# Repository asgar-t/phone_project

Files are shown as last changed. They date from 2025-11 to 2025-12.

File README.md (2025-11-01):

# 📱 Phone Project

A custom embedded hardware project built around an STM32 microcontroller and Quectel EC25 modem.  
The goal is to design, assemble, and program a complete phone system from the ground up — starting with hardware validation and moving toward a full integrated board.

---

## 🚀 Project Overview

**Step 1 — Hardware Verification (current step)** 
- Bring-up of the main board and peripheral circuits  
- Validate power rails, charging system, and USB interface  
- Test modem communication (EC25) and antenna performance  
- Ensure STM32 programming and serial communication are functional  

**Step 2 — Full System Integration**
- Run the STM32 firmware with modem control and battery management  
- Implement power sequencing and graceful shutdown logic  
- Test full end-to-end operation (voice/data + MCU control)  
- Optimize PCB layout and firmware reliability for production

---

## 🧠 Skills Demonstrated
- **PCB Design:** High-speed routing, impedance control, power delivery, and signal integrity  
- **Embedded Programming:** STM32 firmware (C), peripheral interfacing (UART, USB, GPIO, ADC)  
- **Power Systems:** Battery charging, voltage regulation, and load-sharing design  
- **System Integration:** Combining modem, MCU, and power management into a cohesive embedded system  

---

## ⚙️ Technologies & Components
- **MCU:** STM32 L4 Series
- **Modem:** Quectel EC25-AF  
- **Power:** USB-C input, Li-ion battery, charger IC 
- **Communication:** USB, UART, CAN 
- **Tools:** KiCad, STM32CubeIDE

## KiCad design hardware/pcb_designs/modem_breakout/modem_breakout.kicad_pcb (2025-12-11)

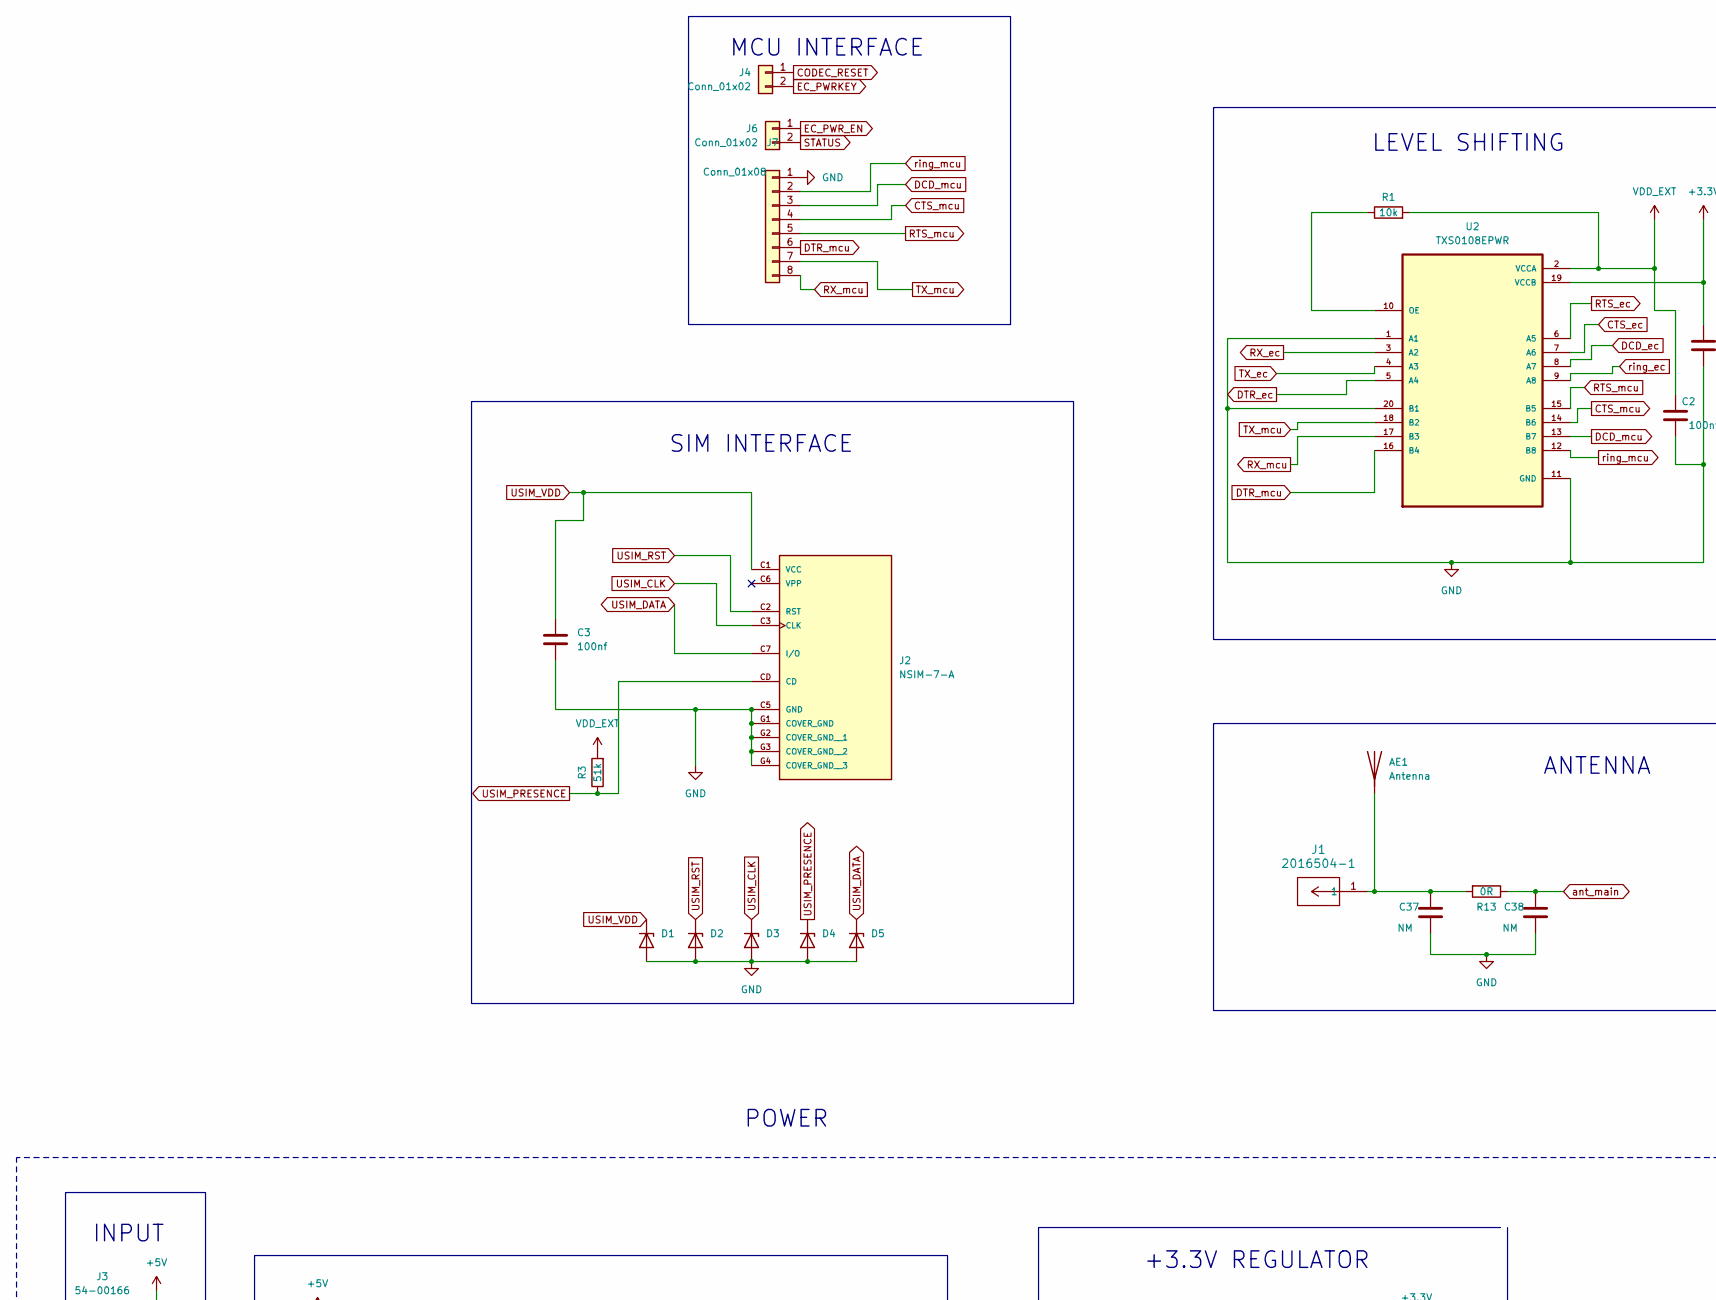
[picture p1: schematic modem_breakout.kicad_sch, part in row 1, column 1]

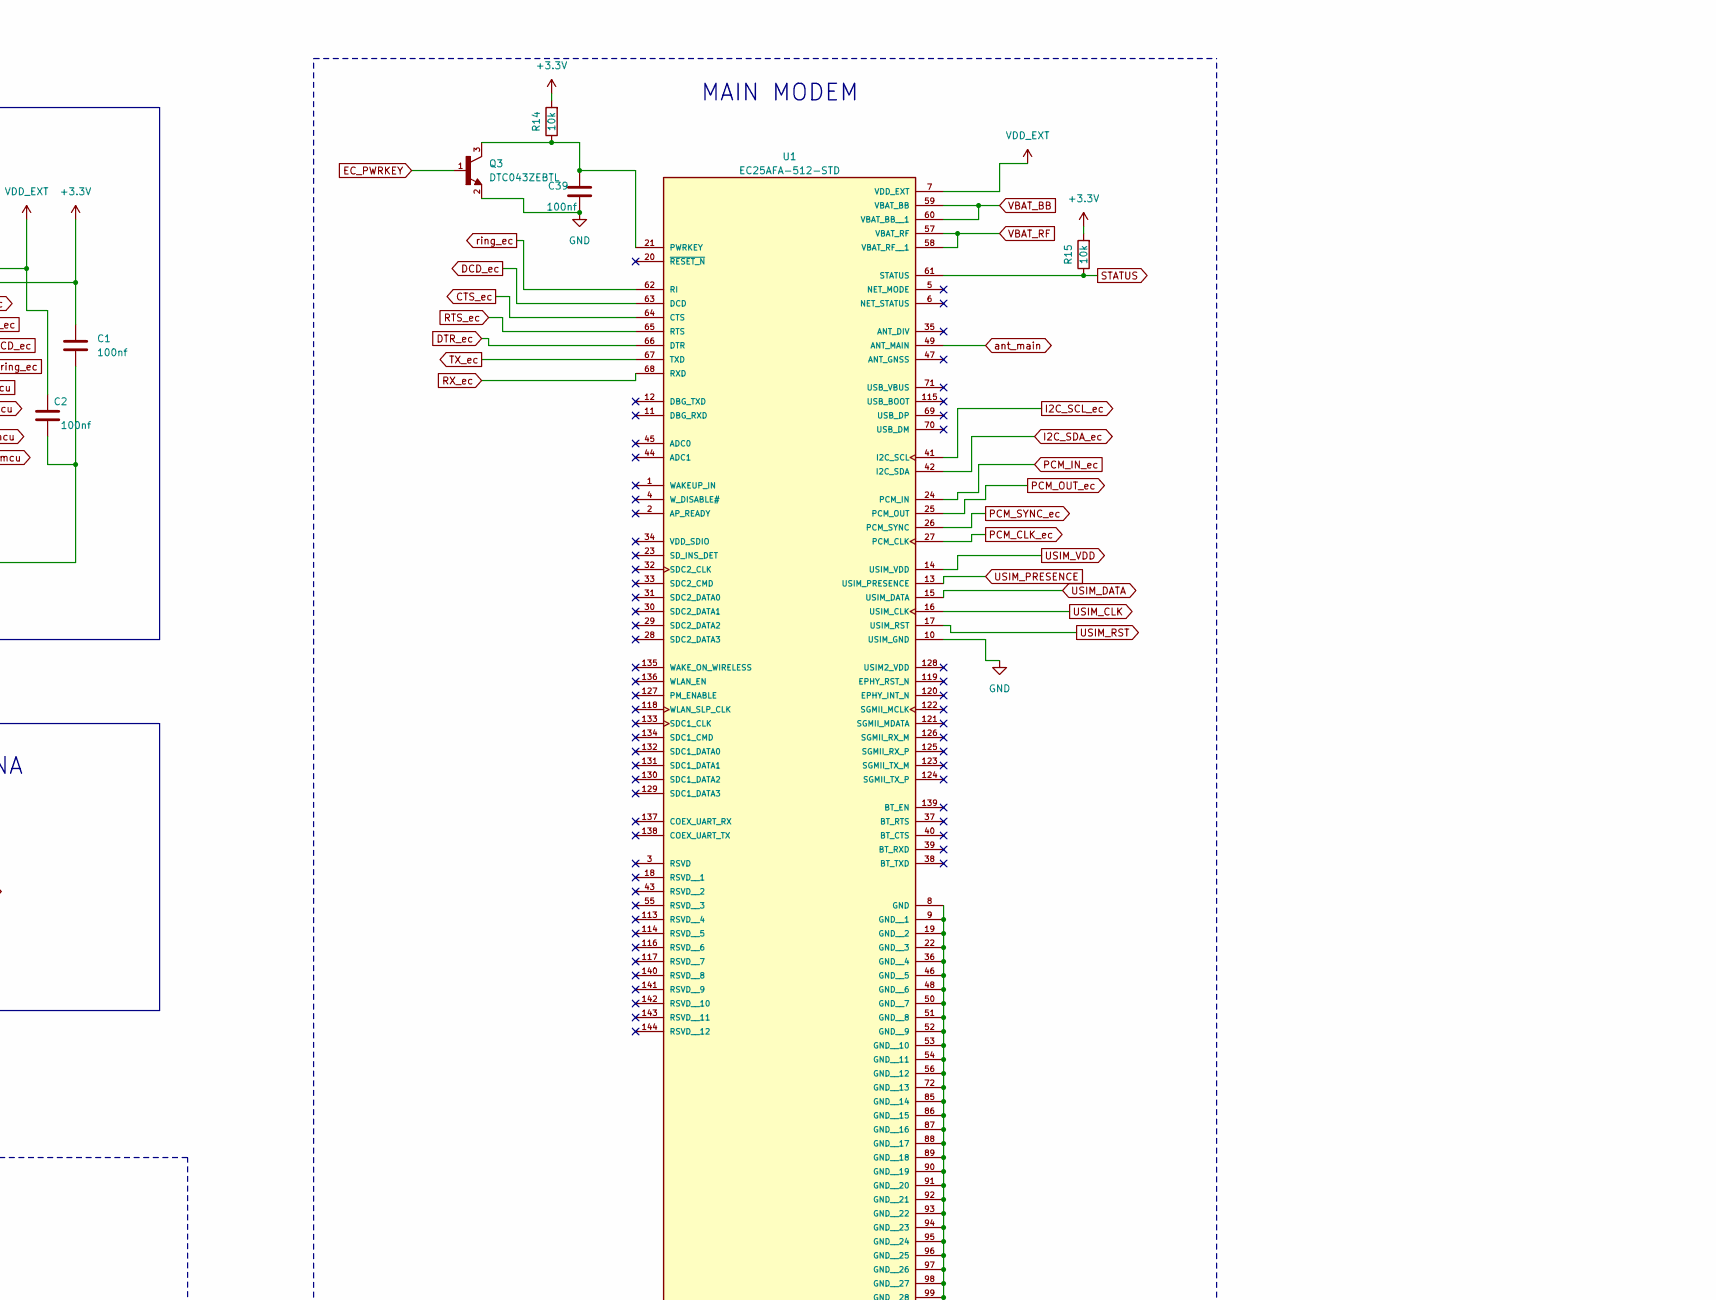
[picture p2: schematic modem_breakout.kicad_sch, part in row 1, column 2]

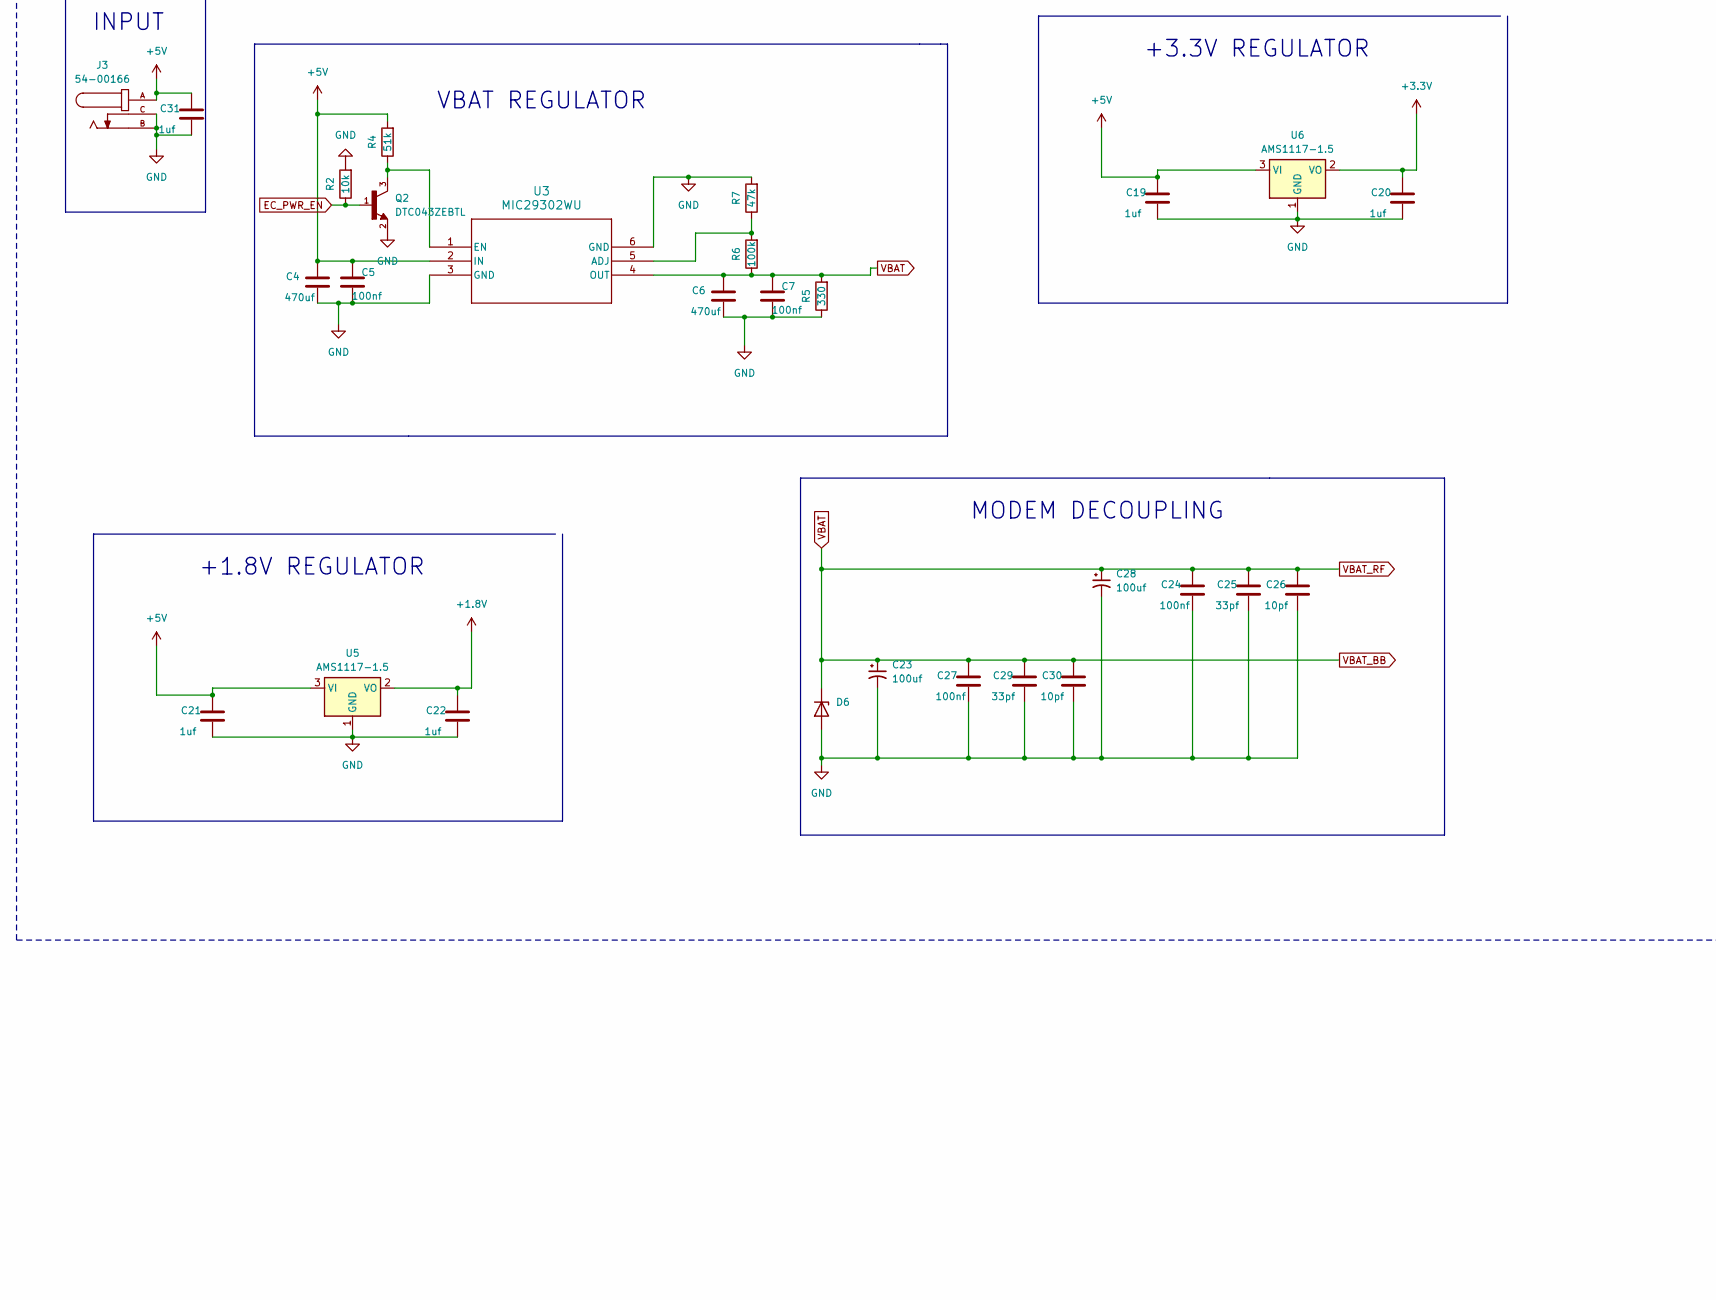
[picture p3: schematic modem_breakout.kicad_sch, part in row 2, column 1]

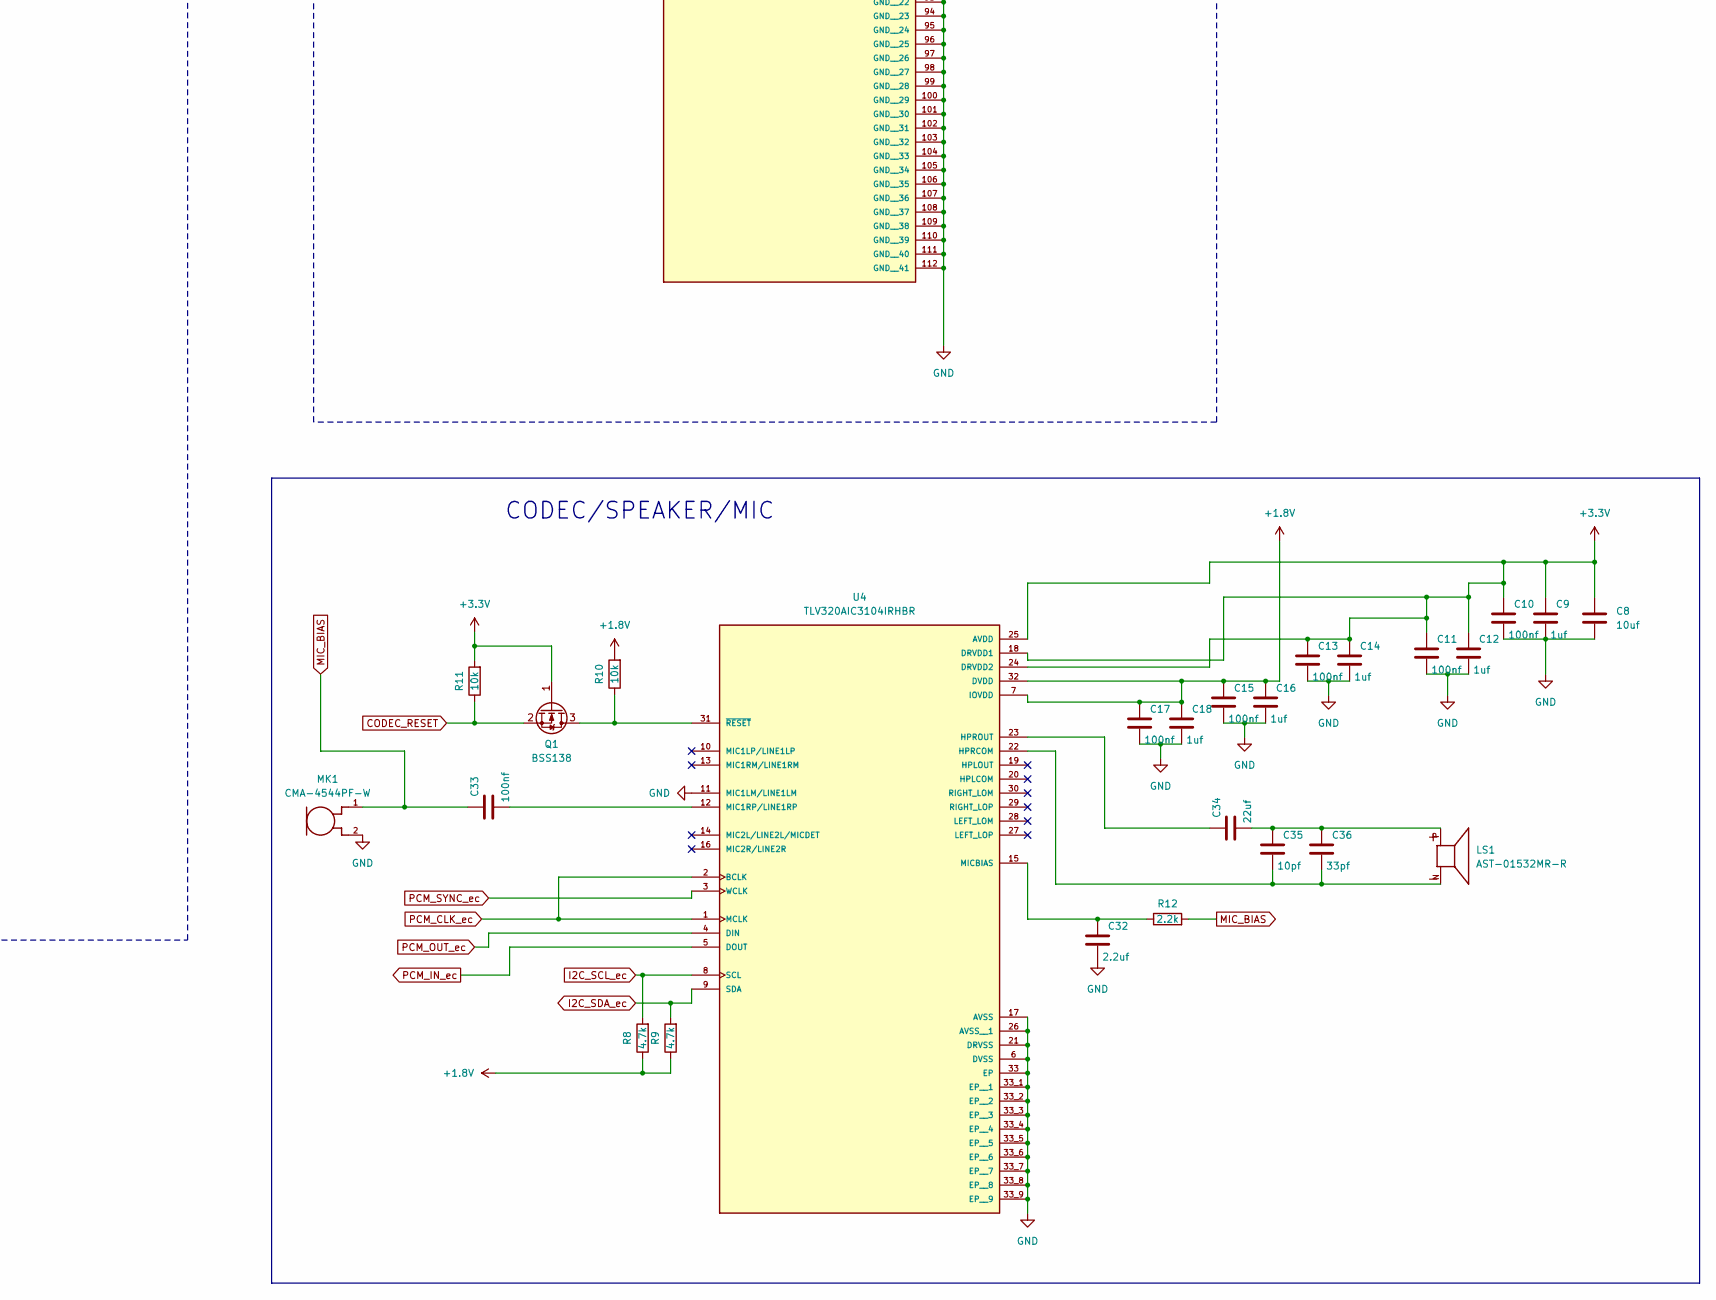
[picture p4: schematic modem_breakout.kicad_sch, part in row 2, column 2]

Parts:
AE1: Antenna
C1, C2, C3, C5, C7, C24, C27, C33, C39: 100nf; C_0805_2012Metric_Pad1.18x1.45mm_HandSolder
C4, C6: 470uf; C_0805_2012Metric_Pad1.18x1.45mm_HandSolder
C8: 10uf; C_0402_1005Metric_Pad0.74x0.62mm_HandSolder
C9, C12, C14, C16, C18: 1uf; C_0402_1005Metric_Pad0.74x0.62mm_HandSolder
C10, C11, C13, C15, C17: 100nf; C_0402_1005Metric_Pad0.74x0.62mm_HandSolder
C19, C20, C21, C22, C31: 1uf; C_0805_2012Metric_Pad1.18x1.45mm_HandSolder
C23, C28: 100uf; C_0805_2012Metric_Pad1.18x1.45mm_HandSolder
C25, C29, C36: 33pf; C_0805_2012Metric_Pad1.18x1.45mm_HandSolder
C26, C30, C35: 10pf; C_0805_2012Metric_Pad1.18x1.45mm_HandSolder
C32: 2.2uf; C_0805_2012Metric_Pad1.18x1.45mm_HandSolder
C34: 22uf; C_0805_2012Metric_Pad1.18x1.45mm_HandSolder
C37, C38: NM; C_0805_2012Metric_Pad1.18x1.45mm_HandSolder
D1, D2, D3, D4, D5, D6: PTVS12VZ1USK; Nexperia_DSN1608-2_1.6x0.8mm
J1: 2016504-1; CONN1_2016504-1_TEC
J2: NSIM-7-A; new_sim; PARTREV 1.0
J3: 54-00166; barrel jack; PARTREV A
J4, J6: Conn_01x02; PinHeader_1x02_P2.54mm_Vertical
J7: Conn_01x08; PinHeader_1x08_P2.54mm_Vertical
LS1: AST-01532MR-R; SPKR_AST-01532MR-R; PARTREV A
MK1: CMA-4544PF-W; MIC_CMA-4544PF-W
Q1: BSS138; SOT-23
Q2, Q3: DTC043ZEBTL; SOTFL50P160X85-3N; PARTREV 002
R1, R2, R14, R15: 10k; C_0805_2012Metric_Pad1.18x1.45mm_HandSolder
R3, R4: 51k; C_0805_2012Metric_Pad1.18x1.45mm_HandSolder
R5: 330; C_0805_2012Metric_Pad1.18x1.45mm_HandSolder
R6: 100k; C_0805_2012Metric_Pad1.18x1.45mm_HandSolder
R7: 47k; C_0805_2012Metric_Pad1.18x1.45mm_HandSolder
R8, R9: 4.7k; C_0805_2012Metric_Pad1.18x1.45mm_HandSolder
R10, R11: 10k; C_0402_1005Metric_Pad0.74x0.62mm_HandSolder
R12: 2.2k; C_0805_2012Metric_Pad1.18x1.45mm_HandSolder
R13: 0R; C_0805_2012Metric_Pad1.18x1.45mm_HandSolder
U1: EC25AFA-512-STD; modem
U2: TXS0108EPWR; uart_translator
U3: MIC29302WU; vreg
U4: TLV320AIC3104IRHBR; new_codec
U5, U6: AMS1117-1.5; SOT-223-3_TabPin2

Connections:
+1.8V: C15.1, C16.1, C17.1, C18.1, C22.1, R8.1, R9.1, R10.2, U4.7 (IOVDD), U4.32 (DVDD), U5.2 (VO)
+3.3V: C1.1, C8.1, C9.1, C10.1, C11.1, C12.1, C13.1, C14.1, C20.1, Q1.1 (G), R11.2, R14.2, R15.2, U2.19 (VCCB), U4.18 (DRVDD1), U4.24 (DRVDD2), U4.25 (AVDD), U6.2 (VO)
+5V: C4.1, C5.1, C19.1, C21.1, C31.1, J3.A, R4.2, U3.2 (IN), U5.3 (VI), U6.3 (VI)
CODEC_RESET: J4.1, Q1.2 (S), R11.1
CTS_ec: U1.64 (CTS), U2.7 (A6)
CTS_mcu: J7.4, U2.14 (B6); also elsewhere on the board
DCD_ec: U1.63 (DCD), U2.8 (A7)
DCD_mcu: J7.3, U2.13 (B7); also elsewhere on the board
DTR_ec: U1.66 (DTR), U2.5 (A4)
DTR_mcu: J7.6, U2.16 (B4); also elsewhere on the board
EC_PWRKEY: J4.2, Q3.1
EC_PWR_EN: J6.1, Q2.1, R2.1
GND: C1.2, C2.2, C3.2, C4.2, C5.2, C6.2, C7.2, C8.2, C9.2, C10.2, C11.2, C12.2, C13.2, C14.2, C15.2, C16.2, C17.2, C18.2, C19.2, C20.2, C21.2, C22.2, C23.2, C24.2, C25.2, C26.2, C27.2, C28.2, C29.2, C30.2, C31.2, C32.2, C37.2, C38.2, C39.2, D1.2 (A), D2.2 (A), D3.2 (A), D4.2 (A), D5.2 (A), D6.2 (A), J2.C5 (GND), J2.G1 (COVER_GND), J2.G2 (COVER_GND__1), J2.G3 (COVER_GND__2), J2.G4 (COVER_GND__3), J3.B, J3.C, J7.1, MK1.2, Q2.2, Q3.2, R2.2, R5.1, R7.2, U1.8 (GND), U1.9 (GND__1), U1.10 (USIM_GND), U1.19 (GND__2), U1.22 (GND__3), U1.36 (GND__4), U1.46 (GND__5), U1.48 (GND__6), U1.50 (GND__7), U1.51 (GND__8), U1.52 (GND__9), U1.53 (GND__10), U1.54 (GND__11), U1.56 (GND__12), U1.72 (GND__13), U1.85 (GND__14), U1.86 (GND__15), U1.87 (GND__16), U1.88 (GND__17), U1.89 (GND__18), U1.90 (GND__19), U1.91 (GND__20), U1.92 (GND__21), U1.93 (GND__22), U1.94 (GND__23), U1.95 (GND__24), U1.96 (GND__25), U1.97 (GND__26), U1.98 (GND__27), U1.99 (GND__28), U1.100 (GND__29), U1.101 (GND__30), U1.102 (GND__31), U1.103 (GND__32), U1.104 (GND__33), U1.105 (GND__34), U1.106 (GND__35), U1.107 (GND__36), U1.108 (GND__37), U1.109 (GND__38), U1.110 (GND__39), U1.111 (GND__40), U1.112 (GND__41), U2.1 (A1), U2.11 (GND), U2.20 (B1), U3.3 (GND), U3.6 (GND), U4.6 (DVSS), U4.11 (MIC1LM/LINE1LM), U4.17 (AVSS), U4.21 (DRVSS), U4.26 (AVSS__1), U4.33 (EP), U4.33_1 (EP__1), U4.33_2 (EP__2), U4.33_3 (EP__3), U4.33_4 (EP__4), U4.33_5 (EP__5), U4.33_6 (EP__6), U4.33_7 (EP__7), U4.33_8 (EP__8), U4.33_9 (EP__9), U5.1 (GND), U6.1 (GND); also elsewhere on the board
I2C_SCL_ec: R8.2, U1.41 (I2C_SCL), U4.8 (SCL)
I2C_SDA_ec: R9.2, U1.42 (I2C_SDA), U4.9 (SDA)
MIC_BIAS: C33.1, MK1.1, R12.2
unnamed: AE1.1, C37.1, J1.1, R13.2
unnamed: C34.2, C35.1, C36.1, LS1.P
unnamed: Q1.3 (D), R10.1, U4.31 (~RESET)
unnamed: C39.1, Q3.3, R14.1, U1.21 (PWRKEY)
unnamed: R1.1, U2.10 (OE)
unnamed: R6.2, R7.1, U3.5 (ADJ)
unnamed: Q2.3, R4.1, U3.1 (EN)
unnamed: C35.2, C36.2, LS1.N, U4.22 (HPRCOM)
unnamed: C34.1, U4.23 (HPROUT)
unnamed: C33.2, U4.12 (MIC1RP/LINE1RP)
unnamed: C32.1, R12.1, U4.15 (MICBIAS)
PCM_CLK_ec: U1.27 (PCM_CLK), U4.1 (MCLK), U4.2 (BCLK)
PCM_IN_ec: U1.24 (PCM_IN), U4.5 (DOUT)
PCM_OUT_ec: U1.25 (PCM_OUT), U4.4 (DIN)
PCM_SYNC_ec: U1.26 (PCM_SYNC), U4.3 (WCLK)
RTS_ec: U1.65 (RTS), U2.6 (A5)
RTS_mcu: J7.5, U2.15 (B5); also elsewhere on the board
RX_ec: U1.68 (RXD), U2.3 (A2)
RX_mcu: J7.8, U2.17 (B3); also elsewhere on the board
STATUS: J6.2, R15.1, U1.61 (STATUS)
TX_ec: U1.67 (TXD), U2.4 (A3)
TX_mcu: J7.7, U2.18 (B2); also elsewhere on the board
USIM_CLK: D3.1 (K), J2.C3 (CLK), U1.16 (USIM_CLK)
USIM_DATA: D5.1 (K), J2.C7 (I/O), U1.15 (USIM_DATA)
USIM_PRESENCE: D4.1 (K), J2.CD, R3.1, U1.13 (USIM_PRESENCE)
USIM_RST: D2.1 (K), J2.C2 (RST), U1.17 (USIM_RST)
USIM_VDD: C3.1, D1.1 (K), J2.C1 (VCC), U1.14 (USIM_VDD)
VBAT: C6.1, C7.1, C23.1, C24.1, C25.1, C26.1, C27.1, C28.1, C29.1, C30.1, D6.1 (K), R5.2, R6.1, U1.57 (VBAT_RF), U1.58 (VBAT_RF__1), U1.59 (VBAT_BB), U1.60 (VBAT_BB__1), U3.4 (OUT)
VDD_EXT: C2.1, R1.2, R3.2, U1.7 (VDD_EXT), U2.2 (VCCA)
ant_main: C38.1, R13.1, U1.49 (ANT_MAIN)
ring_ec: U1.62 (RI), U2.9 (A8)
ring_mcu: J7.2, U2.12 (B8); also elsewhere on the board

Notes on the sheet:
MCU INTERFACE
CODEC/SPEAKER/MIC
MODEM DECOUPLING
LEVEL SHIFTING
SIM INTERFACE
MAIN MODEM
ANTENNA
+3.3V REGULATOR
+1.8V REGULATOR
VBAT REGULATOR
POWER
INPUT

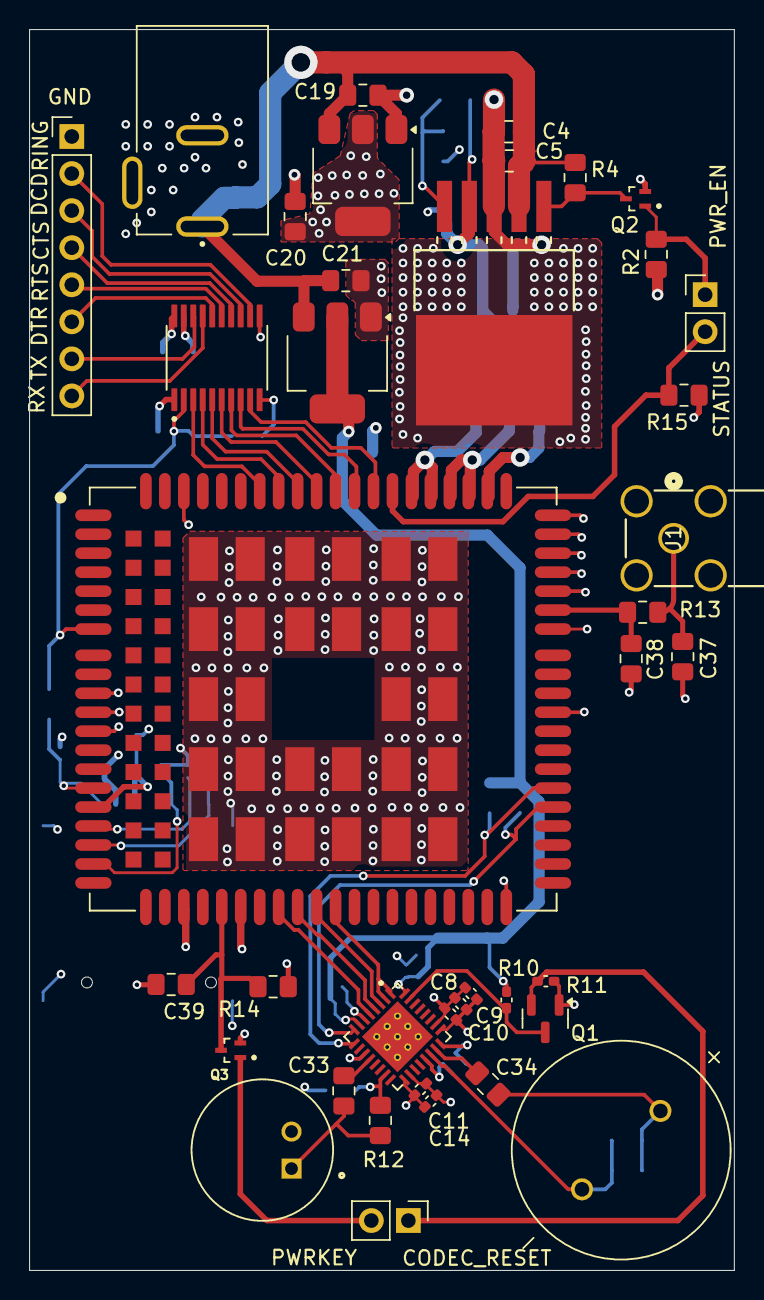
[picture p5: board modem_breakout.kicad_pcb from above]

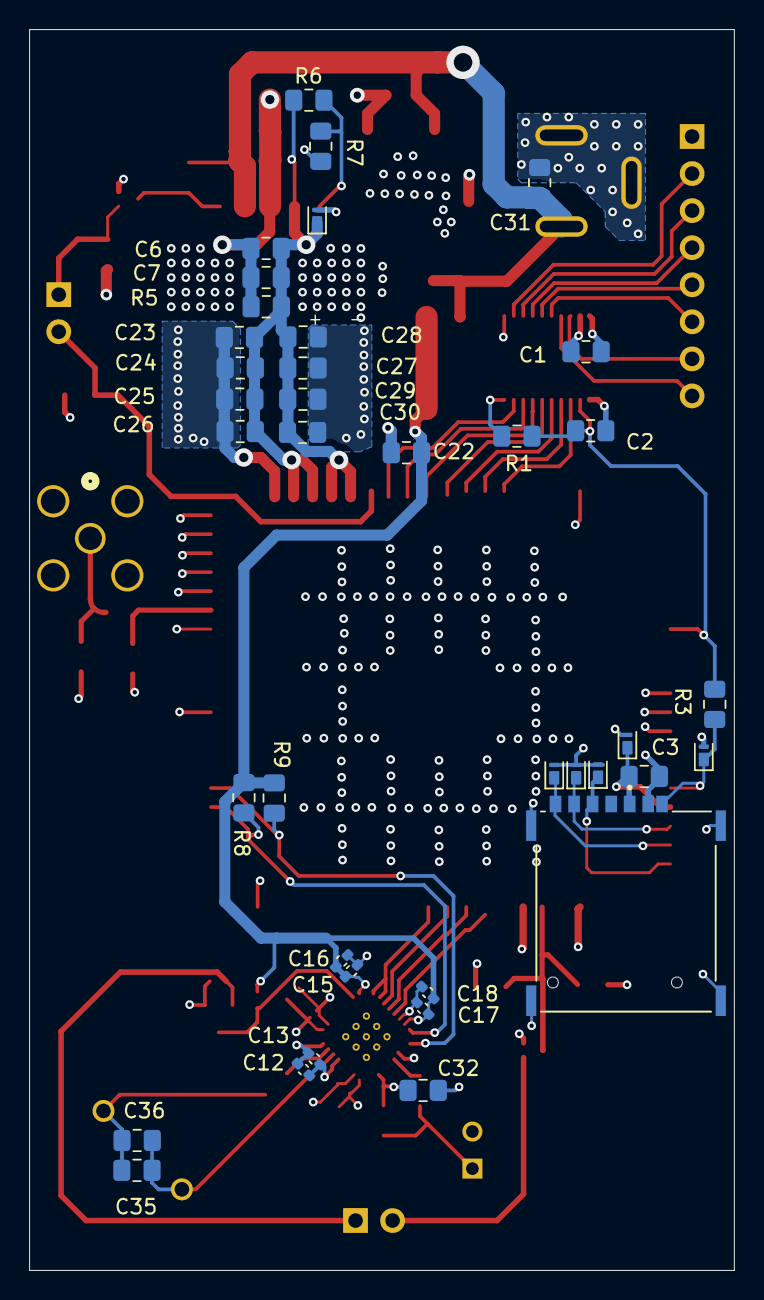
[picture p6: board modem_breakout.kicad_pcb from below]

Board: 4 copper layers, 48.3 x 85.1 mm, 77 parts (38 on the bottom side), 48 nets.

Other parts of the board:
GND: Conn_01x08; PinHeader_1x08_P2.54mm_Vertical

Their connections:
CTS_mcu: GND.4; also elsewhere on the board
DCD_mcu: GND.3; also elsewhere on the board
DTR_mcu: GND.6; also elsewhere on the board
GND: GND.1; also elsewhere on the board
RTS_mcu: GND.5; also elsewhere on the board
RX_mcu: GND.8; also elsewhere on the board
TX_mcu: GND.7; also elsewhere on the board
ring_mcu: GND.2; also elsewhere on the board

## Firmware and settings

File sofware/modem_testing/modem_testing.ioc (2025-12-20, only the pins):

Mcu.UserName=STM32L476RGTx
PA0.Signal=UART4_TX
PA1.Signal=UART4_RX
PA2.GPIO_Label=USART_TX
PA2.Signal=USART2_TX
PA3.GPIO_Label=USART_RX
PA3.Signal=USART2_RX
PA5.GPIO_Label=LD2 [green Led]
PA5.Signal=GPIO_Output
PC13.GPIO_Label=B1 [Blue PushButton]
PC13.Signal=GPXTI13

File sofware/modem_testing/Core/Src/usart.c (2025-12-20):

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
/* Includes ------------------------------------------------------------------*/
#include "usart.h"

/* USER CODE BEGIN 0 */
#include "gpio.h"
#include <string.h>


uint8_t rx_char_pc, rx_char_modem;
uint8_t buffer [BUFFER_SIZE];
uint8_t buffer_index = 0;

void process_message(char* msg);


/* USER CODE END 0 */

UART_HandleTypeDef huart4;
UART_HandleTypeDef huart2;
DMA_HandleTypeDef hdma_usart2_rx;

/* UART4 init function */
void MX_UART4_Init(void)
{

  huart4.Instance = UART4;
  huart4.Init.BaudRate = 115200;
  huart4.Init.WordLength = UART_WORDLENGTH_8B;
  huart4.Init.StopBits = UART_STOPBITS_1;
  huart4.Init.Parity = UART_PARITY_NONE;
  huart4.Init.Mode = UART_MODE_TX_RX;
  huart4.Init.HwFlowCtl = UART_HWCONTROL_NONE;
  huart4.Init.OverSampling = UART_OVERSAMPLING_16;
  huart4.Init.OneBitSampling = UART_ONE_BIT_SAMPLE_DISABLE;
  huart4.AdvancedInit.AdvFeatureInit = UART_ADVFEATURE_NO_INIT;
  if (HAL_UART_Init(&huart4) != HAL_OK)
  {
    Error_Handler();
  }
}
/* USART2 init function */

void MX_USART2_UART_Init(void)
{

  huart2.Instance = USART2;
  huart2.Init.BaudRate = 115200;
  huart2.Init.WordLength = UART_WORDLENGTH_8B;
  huart2.Init.StopBits = UART_STOPBITS_1;
  huart2.Init.Parity = UART_PARITY_NONE;
  huart2.Init.Mode = UART_MODE_TX_RX;
  huart2.Init.HwFlowCtl = UART_HWCONTROL_NONE;
  huart2.Init.OverSampling = UART_OVERSAMPLING_16;
  huart2.Init.OneBitSampling = UART_ONE_BIT_SAMPLE_DISABLE;
  huart2.AdvancedInit.AdvFeatureInit = UART_ADVFEATURE_NO_INIT;
  if (HAL_UART_Init(&huart2) != HAL_OK)
  {
    Error_Handler();
  }
}

void HAL_UART_MspInit(UART_HandleTypeDef* uartHandle)
{

  GPIO_InitTypeDef GPIO_InitStruct = {0};
  RCC_PeriphCLKInitTypeDef PeriphClkInit = {0};
  if(uartHandle->Instance==UART4)
  {
  /** Initializes the peripherals clock
  */
    PeriphClkInit.PeriphClockSelection = RCC_PERIPHCLK_UART4;
    PeriphClkInit.Uart4ClockSelection = RCC_UART4CLKSOURCE_PCLK1;
    if (HAL_RCCEx_PeriphCLKConfig(&PeriphClkInit) != HAL_OK)
    {
      Error_Handler();
    }

    /* UART4 clock enable */
    __HAL_RCC_UART4_CLK_ENABLE();

    __HAL_RCC_GPIOA_CLK_ENABLE();
    /**UART4 GPIO Configuration
    PA0     ------> UART4_TX
    PA1     ------> UART4_RX
    */
    GPIO_InitStruct.Pin = GPIO_PIN_0|GPIO_PIN_1;
    GPIO_InitStruct.Mode = GPIO_MODE_AF_PP;
    GPIO_InitStruct.Pull = GPIO_NOPULL;
    GPIO_InitStruct.Speed = GPIO_SPEED_FREQ_VERY_HIGH;
    GPIO_InitStruct.Alternate = GPIO_AF8_UART4;
    HAL_GPIO_Init(GPIOA, &GPIO_InitStruct);

    /* UART4 interrupt Init */
    HAL_NVIC_SetPriority(UART4_IRQn, 0, 0);
    HAL_NVIC_EnableIRQ(UART4_IRQn);
  }
  else if(uartHandle->Instance==USART2)
  {
  /** Initializes the peripherals clock
  */
    PeriphClkInit.PeriphClockSelection = RCC_PERIPHCLK_USART2;
    PeriphClkInit.Usart2ClockSelection = RCC_USART2CLKSOURCE_PCLK1;
    if (HAL_RCCEx_PeriphCLKConfig(&PeriphClkInit) != HAL_OK)
    {
      Error_Handler();
    }

    /* USART2 clock enable */
    __HAL_RCC_USART2_CLK_ENABLE();

    __HAL_RCC_GPIOA_CLK_ENABLE();
    /**USART2 GPIO Configuration
    PA2     ------> USART2_TX
    PA3     ------> USART2_RX
    */
    GPIO_InitStruct.Pin = USART_TX_Pin|USART_RX_Pin;
    GPIO_InitStruct.Mode = GPIO_MODE_AF_PP;
    GPIO_InitStruct.Pull = GPIO_NOPULL;
    GPIO_InitStruct.Speed = GPIO_SPEED_FREQ_VERY_HIGH;
    GPIO_InitStruct.Alternate = GPIO_AF7_USART2;
    HAL_GPIO_Init(GPIOA, &GPIO_InitStruct);

    /* USART2 DMA Init */
    /* USART2_RX Init */
    hdma_usart2_rx.Instance = DMA1_Channel6;
    hdma_usart2_rx.Init.Request = DMA_REQUEST_2;
    hdma_usart2_rx.Init.Direction = DMA_PERIPH_TO_MEMORY;
    hdma_usart2_rx.Init.PeriphInc = DMA_PINC_DISABLE;
    hdma_usart2_rx.Init.MemInc = DMA_MINC_ENABLE;
    hdma_usart2_rx.Init.PeriphDataAlignment = DMA_PDATAALIGN_BYTE;
    hdma_usart2_rx.Init.MemDataAlignment = DMA_MDATAALIGN_BYTE;
    hdma_usart2_rx.Init.Mode = DMA_NORMAL;
    hdma_usart2_rx.Init.Priority = DMA_PRIORITY_HIGH;
    if (HAL_DMA_Init(&hdma_usart2_rx) != HAL_OK)
    {
      Error_Handler();
    }

    __HAL_LINKDMA(uartHandle,hdmarx,hdma_usart2_rx);

    /* USART2 interrupt Init */
    HAL_NVIC_SetPriority(USART2_IRQn, 0, 0);
    HAL_NVIC_EnableIRQ(USART2_IRQn);
  }
}

void HAL_UART_MspDeInit(UART_HandleTypeDef* uartHandle)
{

  if(uartHandle->Instance==UART4)
  {
    /* Peripheral clock disable */
    __HAL_RCC_UART4_CLK_DISABLE();

    /**UART4 GPIO Configuration
    PA0     ------> UART4_TX
    PA1     ------> UART4_RX
    */
    HAL_GPIO_DeInit(GPIOA, GPIO_PIN_0|GPIO_PIN_1);

    /* UART4 interrupt Deinit */
    HAL_NVIC_DisableIRQ(UART4_IRQn);
  }
  else if(uartHandle->Instance==USART2)
  {
    /* Peripheral clock disable */
    __HAL_RCC_USART2_CLK_DISABLE();

    /**USART2 GPIO Configuration
    PA2     ------> USART2_TX
    PA3     ------> USART2_RX
    */
    HAL_GPIO_DeInit(GPIOA, USART_TX_Pin|USART_RX_Pin);

    /* USART2 DMA DeInit */
    HAL_DMA_DeInit(uartHandle->hdmarx);

    /* USART2 interrupt Deinit */
    HAL_NVIC_DisableIRQ(USART2_IRQn);
  }
}

/* USER CODE BEGIN 1 */
void HAL_UART_RxCpltCallback(UART_HandleTypeDef *huart)
{
	if (huart->Instance == USART2)
	{
		HAL_UART_Transmit(&huart2, &rx_char_pc, 1, HAL_MAX_DELAY);
		if((rx_char_pc == '\b') && (buffer_index > 0))
		{
			buffer_index --;
		}
		else if(rx_char_pc == '\n')
		{
			buffer[buffer_index] = '\0';
			buffer_index = 0;
			process_message((char*)buffer);

		}
		else if(buffer_index < BUFFER_SIZE - 1)
		{
			buffer[buffer_index++] = rx_char_pc;

		}
		  HAL_UART_Receive_DMA(&huart2, &rx_char_pc, 1);

	}
	else if (huart->Instance == UART4)
	{
		HAL_UART_Transmit(&huart2, &rx_char_modem, 1, HAL_MAX_DELAY);
		HAL_UART_Receive_IT(&huart4, &rx_char_modem, 1);

	}
}


void process_message(char* msg){

	if((msg[0] == 'A') && (msg[1] == 'T'))
	{
		HAL_UART_Transmit(&huart4, (uint8_t*)msg, strnlen(msg, BUFFER_SIZE),HAL_MAX_DELAY);

	}
	else
	{
		if (strncmp(msg, "power on\r", BUFFER_SIZE) == 0)
		{
			HAL_UART_Transmit(&huart2, (uint8_t*)"VALID COMMAND\r\n", 15, HAL_MAX_DELAY);

		}
		else if(strncmp(msg, "power off\r", BUFFER_SIZE) == 0)
		{
			HAL_UART_Transmit(&huart2, (uint8_t*)"VALID COMMAND\r\n", 15, HAL_MAX_DELAY);

		}
		else if(strncmp(msg, "power toggle\r", BUFFER_SIZE) == 0)
		{
			HAL_UART_Transmit(&huart2, (uint8_t*)"VALID COMMAND\r\n", 15, HAL_MAX_DELAY);

		}
		else if(strncmp(msg, "codec reset\r", BUFFER_SIZE) == 0)
		{
			HAL_UART_Transmit(&huart2, (uint8_t*)"VALID COMMAND\r\n", 15, HAL_MAX_DELAY);

		}
		else if(strncmp(msg, "status?\r", BUFFER_SIZE) == 0)
		{
			HAL_UART_Transmit(&huart2, (uint8_t*)"VALID COMMAND\r\n", 15, HAL_MAX_DELAY);

		}



		else
		{
			HAL_UART_Transmit(&huart2, (uint8_t*)"INVALID COMMAND\r\n", 17, HAL_MAX_DELAY);

		}




	}



}

/* USER CODE END 1 */

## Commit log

2025-11-01 rework tree
    [modem_breakout.kicad_pcb, modem_breakout.kicad_sch]
2025-11-06 finalize testbench design
    [modem_breakout.kicad_pcb, modem_breakout.kicad_sch]
2025-11-07 final - ordered
    [modem_breakout.kicad_pcb, modem_breakout.kicad_sch]
2025-11-07 uart/putty working
2025-12-11 modem/putty interface
    [modem_breakout.kicad_pcb]
2025-12-20 uart interface set up

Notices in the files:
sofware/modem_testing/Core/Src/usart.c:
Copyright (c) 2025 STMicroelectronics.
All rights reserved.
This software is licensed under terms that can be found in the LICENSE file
